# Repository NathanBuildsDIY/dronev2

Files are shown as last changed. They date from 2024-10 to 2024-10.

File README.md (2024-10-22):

See the accompanying youtube video series on @NathanBuildsDIY channel for details on how to build all of this and get it going - https://youtu.be/KzYfzi7Ct5Y
There are 5 parts

1. Collect parts - 3d print all the files here on a large format 3d printer, buy the motors/raspberry pi/drone parts in the parts list
2. Assemble the drone and landing pad per the youtube video.  See electrical schematics here as well.
3. Set up windows laptop + arduino that's used to control the drone and landing pad/battery swap station
4. Set up the raspberry pi, collect sample images and train your custom image classification model to identify the weeds in your field
5. Create waypoints files to cover your field and deploy the drone to spray weeds!

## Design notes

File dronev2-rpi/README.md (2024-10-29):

1. Log into your new raspberry pi zero 2 w
2. sudo apt-get -y install git #<-- install git
3. git clone https://github.com/NathanBuildsDIY/dronev2 #<-- pull down this git to the rpi
4. mv dronev2/dronev2-rpi . #<-- pull out the dronev2-rpi directyory from this repo to its own directory 
5. bash install_rpi_drone.sh #<-- run the setup script. It will install all libraries and set up the pi to auto-run the script that takes photos and (if the tflite model is present) classify those photos and turn on the sprayer

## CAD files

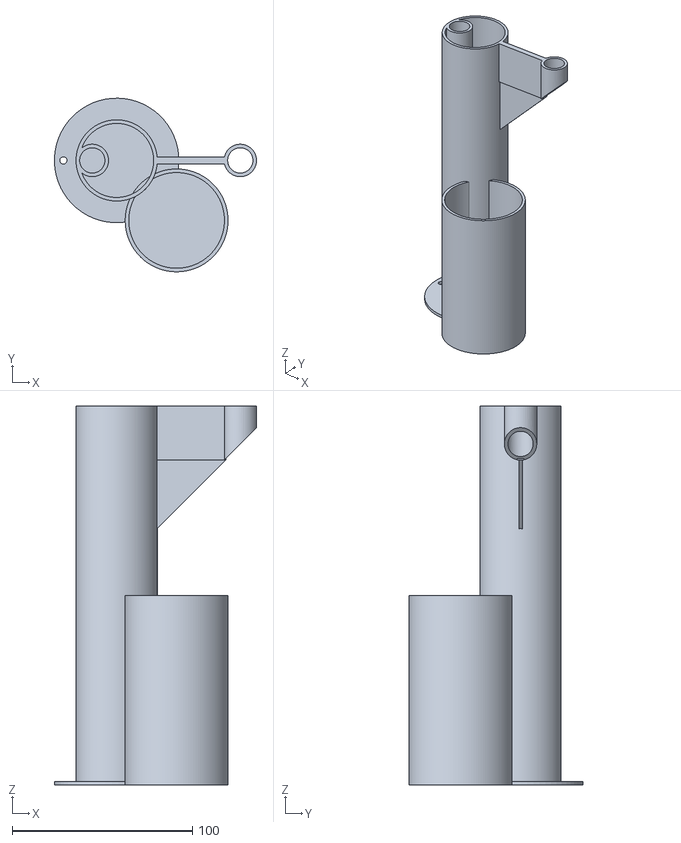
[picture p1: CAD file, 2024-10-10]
3D-Models/droneCup.stl
112.0 x 96.2 x 210.0

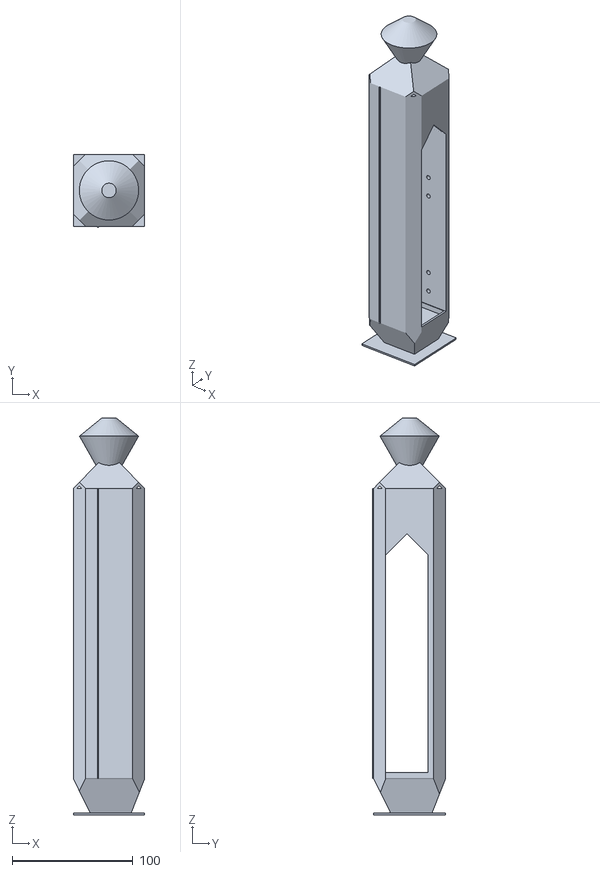
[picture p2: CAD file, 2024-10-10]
3D-Models/droneBatteryCage_v2.4.stl
59.0 x 60.5 x 328.2

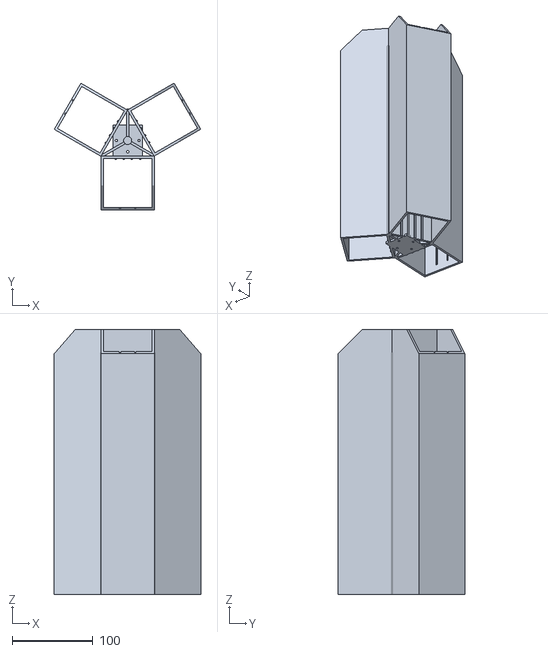
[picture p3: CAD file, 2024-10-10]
3D-Models/droneChargerSpinner_v2.1.stl
181.5 x 157.2 x 328.2

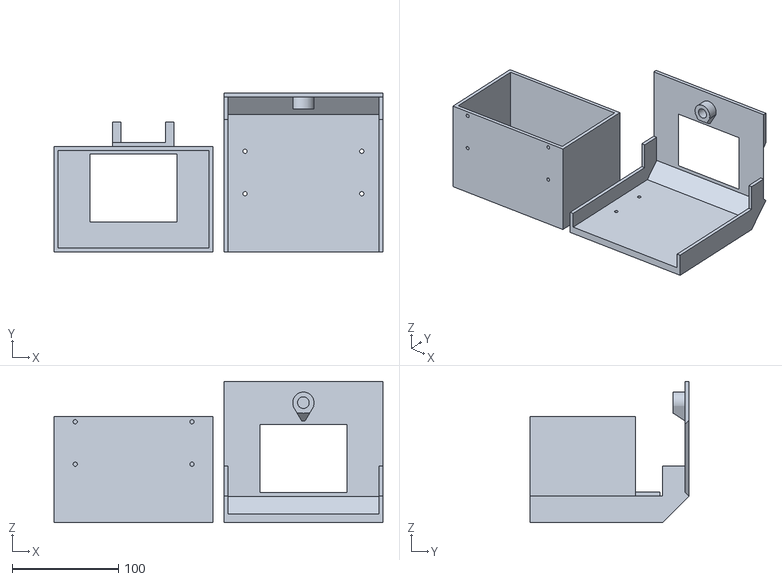
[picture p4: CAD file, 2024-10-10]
3D-Models/droneMotorSpinnerHarness_v2.stl
310.0 x 150.0 x 133.0

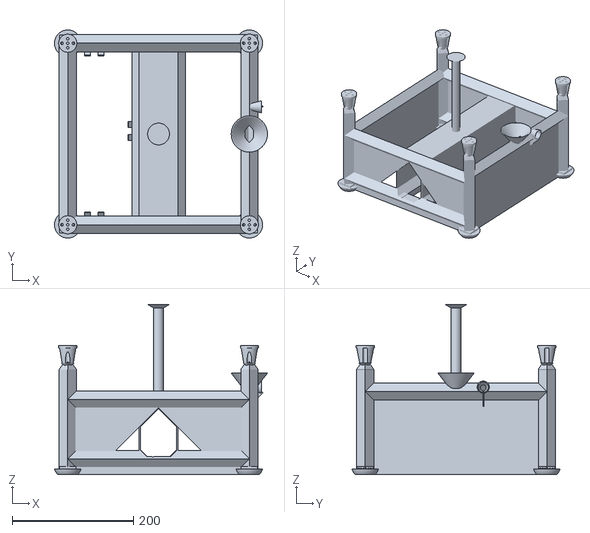
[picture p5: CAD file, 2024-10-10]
3D-Models/droneBase_v2.3.stl
351.9 x 343.8 x 281.2

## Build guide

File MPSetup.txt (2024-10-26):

Mission planner set up. 
	Great references - ardupilot - initial setup and first flight pages.  https://ardupilot.org/copter/docs/initial-setup.html
  Install mission planner
  Firmware load (usb).  Frame type. 
Remove the USB cable from your cube orange, we're going to try to conn ct to it via the 900MHz radio instead.  connect the battery to your drone to power it up then plug your 900mhz radio into your laptop via the USB port. You may havccc v cto install some drivers for the 900mhz radio via USB or you may have to read a bit on the ardupilot pages about configuration, but for me windows grabbed the drivers and it connected when I had mission planner "auto" connected to the drone, no configuration required    c 7u[ cv  b   v cccccccccccccccccccccccccccccccccccccccccccccccccccc v    
  Special setup for orange/here3+  New setup: cube orange/here3
    https://docs.cubepilot.org/user-guides/here-3/here-3-manual - had to make changes to     parm list to get here3 recognized and used.
CAN_D1_PROTOCOL: 1 set virtual driver of CAN1 to DRONECAN
CAN_D2_PROTOCOL: 1 set virtual driver of CAN 2 to DRONECAN
CAN_P1_DRIVER: 1 set this parameter to enable CAN 1 bus
CAN_P2_DRIVER: 1 set this parameter to enable CAN 2 bus
GPS_TYPE: 9 set the communication protal type of GPS 1 to DRONECAN
NTF_LED_TYPES: 231 Set to DRONECAN for LED type
There is no external safety switch. Set BRD_SAFETYENABLE as 0 to disable safety switch, or connect an physical external safety switch
Click "Write Params" when done. CAN functions will be available after rebooting the flight controller.
    Also setup for new cube orange
    fs_thr_enable - disable to allow no rc controller
    arming_check - disable check boxes
    brd_safetyenable - disable
    Then may have to disable "other" gps though it results in higher ekf
  Connect via radio.  accel, compass, esc cal (skip radio - we don't have controls to fly)
  Special configuration to auto fly. 
	initial setup - flight modes
	failsafes
	prearm safety check
	Other settings to customize
	AUTO_OPTIONS: Auto mode options
	0     Allow Arming
	1     Allow Takeoff Without Raising Throttle
	2     Ignore pilot yaw
 	   Object Detection - Connect to gps2 on cube orange.  (serial 4). 
	   SERIAL4_PROTOCOL = 9 OLD SETTINGS: ORANGE 5  (serial3 = gps, 5) (serial 1/2 = 1)
 	   SERIAL4_BAUD = 115 OLD SETTINGS: ORANGE 38 (serial3 = 38)  (serial1/2 = 57)
 	   RNGFND1_TYPE = 20     YES THIS ONE ONLY ON ORANGE
 	   RNGFND1_MIN_CM = 10
 	   RNGFND1_MAX_CM = 300
 	   RNGFND1_GNDCLEAR = 10
 	   TEST SONAR = flight control, status, sonarrange (17.95?), sonarvoltage
  Leica/base station.

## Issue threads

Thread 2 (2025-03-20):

Bridging the gap between tech and farmers

moreltay, 2025-03-20:
Nathan,

I came across your youtube channel and your amazing autonomous drone sprayer.
I am the founder of Agri Spray Drones. We one of the largest suppliers of spray drones in the country.
Our mission is to Empower Rural America and we do that through providing this technology which creates opportunities for people in rural communities to start businesses providing application services to farmers.

We also have a youtube channel dedicated mostly to educating farmers on the different drone tech available, features and benefits, and use cases.
Here is a spot spraying video of a job that we did that is similar to what your drone does, with much less automation of course. https://www.youtube.com/watch?v=cEvHZr4KTSc&t

Most of our drones are much larger than yours, carrying close to 20 gallons and designed for broad acre application.
I have started working on a very similar project to yours for automated refill and battery swap of our large drones. We are working with a drone manufacturer now that allows us much more flexibility on software and hardware customizations.

I would very much so be interested in working with you to create a much larger version of your automated drone system. I believe this would be a huge benefit for farmers to reduce costs and chemical use. That is what they want, but we have to make it easy to use and to understand.

I would really like to meet with you to talk about your drone project.
Here is my email and cell phone number. Please let me know when you have time for a call.
taylor@agrispraydrones.com
816-258-3296

PS. I am also a bit of a DIY creator. I have a non profit where I create mobility devices for children with disabilities. You can see more here.
https://www.facebook.com/frogmobilityllc
https://thefrogfoundation.org/

Thank you,
Taylor Moreland

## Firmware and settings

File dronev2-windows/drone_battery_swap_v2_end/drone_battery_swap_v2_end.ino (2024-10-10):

#include <ezButton.h>
#include <Servo.h>
// initialize pins
int generic_dir = 6;
int leftBat = 5;
int rightBat = 8;
int farArm1 = 11; 
int nearArm1 = 7;
int water = 12;
int arm2 = 9;
int relaunch = 10;
int relaunchL = 4;
int demo = 0;
int demoButton = 3; int demoButtonState = 0;
int fullRun = 1;
//Servo lBatSpin;
//Servo rBatSpin;
//ezButton landing2_limit(13); //history

// the setup function runs once when you press reset or power the board
void setup() 
{
  pinMode(generic_dir, OUTPUT); 
  pinMode(leftBat, OUTPUT); 
  pinMode(rightBat, OUTPUT);
  pinMode(farArm1, OUTPUT); 
  pinMode(nearArm1, OUTPUT);
  pinMode(water, OUTPUT);
  pinMode(arm2, OUTPUT);
  pinMode(relaunch, OUTPUT);
  pinMode(relaunchL, OUTPUT); 
  pinMode(demoButton, INPUT);
  pinMode(LED_BUILTIN, OUTPUT);
  //lBatSpin.attach(A1);
  //rBatSpin.attach(A0);
  //landing2_limit.setDebounceTime(10); //history
  Serial.begin(9600);
}

// the loop function runs over and over again forever
void loop() 
{ 
  //3. push back out onto landing pad  estimate 5 mins
  if (demo == 1){waitForPress();}//wait for demo button to be pushed if demo is active
  moveMotor(generic_dir, arm2, 255, 70000, 0); //pull back retrieve arm, clear space on pad
  moveMotor(generic_dir, arm2, 145, 5000, 0); //slow to limit
  if (demo == 1){waitForPress();}//wait for demo button to be pushed if demo is active
  moveMotor2(generic_dir, relaunch, 255, relaunchL, 255, 95000, 0); //push drone out onto pad with arm
  moveMotor2(generic_dir, relaunch, 255, relaunchL, 255, 100000, 1); //retract arm
  if (demo == 1){waitForPress();}//wait for demo button to be pushed if demo is active
  moveMotor2(generic_dir, farArm1, 255, nearArm1, 255, 30000, 0); //move short arms back out to clear space for takeoff
  moveMotor2(generic_dir, farArm1, 100, nearArm1, 145, 4000, 0); //slow to limit
  exit(0);
}

void waitForPress(){
  //waits for button to be pressed in demo mode
  Serial.print("waiting for button push");
  demoButtonState = digitalRead(demoButton);
  while(demoButtonState == LOW) {
    demoButtonState = digitalRead(demoButton);
    digitalWrite(LED_BUILTIN, HIGH);
    delay(300);
    digitalWrite(LED_BUILTIN, LOW);
    delay(300);
  }
}

int moveMotor(int dir_pin, int pwm_pin, int speed, long milliseconds, int dir){
  //move a single motor for a given time
  //set motor direction
  if (dir == 1) {
    digitalWrite(dir_pin, HIGH);
  }
  else {
    digitalWrite(dir_pin, LOW);
  }
  analogWrite(pwm_pin, speed); //start motor movin
  delay(milliseconds); //delay for duration desired
  analogWrite(pwm_pin, 0); //stop motor movin
  delay(1000); // let the power supply and motors sit idle for a moment
  return 1;
}

int moveMotor2(int dir_pin, int pwm1_pin, int pwm1_speed, int pwm2_pin, int pwm2_speed, long milliseconds, int dir){
  //start and stop moving 2 motors at the same time, run them for a given time
  //set motor direction
  if (dir == 1) {
    digitalWrite(dir_pin, HIGH);
  }
  else {
    digitalWrite(dir_pin, LOW);
  }
  analogWrite(pwm1_pin, pwm1_speed); //start motor1 moving
  analogWrite(pwm2_pin, pwm2_speed); //start motor2 moving
  delay(milliseconds); //delay for duration desired
  analogWrite(pwm1_pin, 0); //stop motor1 moving
  analogWrite(pwm2_pin, 0); //stop motor2 moving
  delay(1000); // let the power supply and motors sit idle for a moment
  return 1;
}

int moveMotor2Start(int dir_pin, int pwm1_pin, int pwm1_speed, int pwm2_pin, int pwm2_speed, long milliseconds, int dir){
  //start moving 2 motors at the same time, no stop time set
  //set motor direction
  if (dir == 1) {
    digitalWrite(dir_pin, HIGH);
  }
  else {
    digitalWrite(dir_pin, LOW);
  }
  analogWrite(pwm1_pin, pwm1_speed); //start motor1 moving
  analogWrite(pwm2_pin, pwm2_speed); //start motor2 moving
  delay(1000); // let the power supply and motors sit idle for a moment
  return 1;
}

int moveMotor2Stop(int pwm1_pin, int pwm2_pin){
  //stop moving 2 motors at the same time
  analogWrite(pwm1_pin, 0); //stop motor1 moving
  analogWrite(pwm2_pin, 0); //stop motor2 moving
  delay(1000); // let the power supply and motors sit idle for a moment
  return 1;
}

int moveMotorLimit(int dir_pin, int pwm_pin, long milliseconds, int dir, ezButton limitSwitch){
  //move motor to a limit switch. 
  //set motor direction
  if (dir == 1) {
    digitalWrite(dir_pin, HIGH);
  }
  else {
    digitalWrite(dir_pin, LOW);
  }
  long startMillis = millis(); //get initial time
  long currentMillis = millis();
  limitSwitch.loop();
  int initState = limitSwitch.getState(); //get initial state
  int curState = limitSwitch.getState(); 
  analogWrite(pwm_pin, 255); //start motor moving
  //turn on motor until the milliseconds are pass OR the limit switch is hit
  while((currentMillis - startMillis <= milliseconds) && (initState == curState)) {
    limitSwitch.loop();
    curState = limitSwitch.getState();
    currentMillis = millis();
  }
  analogWrite(pwm_pin, 0); //stop motor moving
  delay(1000); // let the power supply and motors sit idle for a moment
  return 1;
}

int moveMotorLimit2(int dir_pin, int pwm1_pin, int pwm1_speed, int pwm2_pin, int pwm2_speed, long milliseconds, int dir, ezButton limitSwitch1, ezButton limitSwitch2){
  //move 2 motors to a limit switch, each will turn off when its limit is hit, but the other can continue running to limit even if the first is already there and stopped
  //set motor direction
  if (dir == 1) {
    digitalWrite(dir_pin, HIGH);
  }
  else {
    digitalWrite(dir_pin, LOW);
  }
  long startMillis = millis(); //get initial time
  long currentMillis = millis();
  limitSwitch1.loop();
  limitSwitch2.loop();
  int initState1 = limitSwitch1.getState(); //get initial state 1
  int curState1 = limitSwitch1.getState(); //get cur state 1
  int initState2 = limitSwitch2.getState(); //get initial state 2
  int curState2 = limitSwitch2.getState(); //get cur state 2
  analogWrite(pwm1_pin, pwm1_speed); //start motor1 moving
  analogWrite(pwm2_pin, pwm2_speed); //start motor2 moving
  //turn on motors until the milliseconds are passed OR the limit switches are hit
  int counterLimit1 = 0;
  int counterLimit2 = 0;
  while((currentMillis - startMillis <= milliseconds) && ((counterLimit1 == 0) || (counterLimit2 == 0))) {
    limitSwitch1.loop();
    limitSwitch2.loop();
    curState1 = limitSwitch1.getState();
    curState2 = limitSwitch2.getState();
    if(initState1 != curState1){
      analogWrite(pwm1_pin, 0); //limit reached, stop motor1 moving
      counterLimit1 = 1;
    }
    if(initState2 != curState2){
      analogWrite(pwm2_pin, 0); //limit reached, stop motor2 moving
      counterLimit2 = 1;
    }
    currentMillis = millis();
  }
  analogWrite(pwm1_pin, 0); //stop motor1 moving
  analogWrite(pwm2_pin, 0); //stop motor2 moving
  delay(1000); // let the power supply and motors sit idle for a moment
  return 1;
}

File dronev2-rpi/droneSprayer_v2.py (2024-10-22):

import os
import time
from picamera2 import Picamera2, Preview
from datetime import datetime
from tflite_support.task import core
from tflite_support.task import processor
from tflite_support.task import vision
import cv2
import os
import os.path
import imutils
from gpiozero import LED

#set up camera
camera = Picamera2() #declare camera
config = camera.create_preview_configuration()
#camwidth = 1440 
#camheight = 1080
#config = picam.create_preview_configuration(main={"size": (camwidth, camheight)})
camera.configure(config)
camera.start()

#create run directory to save photos and go there
dronedir = os.path.expanduser("~/dronev2-rpi/")
date = datetime.now().strftime("%m_%d_%I_%M_%S_%p_%f")
rundir = dronedir+date
os.makedirs(rundir)
os.chdir(rundir)

#define sprayer pin
sprayer = LED(14)
sprayer.off()

#decide if there is an image classification model
imageModelPresent = False
if os.path.isfile(dronedir + "model_int8.tflite"):
  imageModelPresent = True
  print("Image Classification Model Exists, load it")
  # Initialize the image classification model. This is the custom trained model based on mobilenet
  base_options = core.BaseOptions(
    file_name=os.path.expanduser('~/dronev2-rpi/model_int8.tflite'), use_coral=False, num_threads=4)
  # Enable Coral by this setting
  classification_options = processor.ClassificationOptions(
    max_results=2, score_threshold=0.0)
  options = vision.ImageClassifierOptions(
    base_options=base_options, classification_options=classification_options)
  classifier = vision.ImageClassifier.create_from_options(options) 

while True:
  #take a photo
  date = datetime.now().strftime("%m_%d_%I_%M_%S_%p_%f") #note: keep it short and don't allow : in filename - error
  photo_name = date + ".jpg"
  camera.capture_file(photo_name)

  if imageModelPresent == True: 
    #Load the image
    image = cv2.imread(photo_name) #pull up image and get shape

    # Convert the image from BGR to RGB as required by the TFLite model.
    rgb_image = cv2.cvtColor(image, cv2.COLOR_BGR2RGB)
    re_size = (224,224)
    rgb_image=cv2.resize(rgb_image,re_size)

    # Create TensorImage from the RGB image
    tensor_image = vision.TensorImage.create_from_array(rgb_image)
    # List classification results
    categories = classifier.classify(tensor_image)
    category = categories.classifications[0].categories[0]

    #Label Image
    category_name = category.category_name
    score = round(category.score, 2)
    result_text = category_name + ' (' + str(score) + ')'

    #If Weed, turn on sprayer
    if category_name.startswith("weed") and score > 0.6:
      print("Found weed, turning on sprayer")
      sprayer.on()
      cv2.putText(image,category_name,(10,200),cv2.FONT_HERSHEY_PLAIN, 4, (0,0,255), 8) #image, text, (x,y), fontname, fontsize, color, thickness)
      cv2.putText(image,str(score),(10,400),cv2.FONT_HERSHEY_PLAIN, 4, (0,0,255), 8) #image, text, (x,y), fontname, fontsize, color, thickness)
    else:
      sprayer.off()
      cv2.putText(image,category_name,(10,200),cv2.FONT_HERSHEY_PLAIN, 4, (0,255,0), 8) #image, text, (x,y), fontname, fontsize, color, thickness)
      cv2.putText(image,str(score),(10,400),cv2.FONT_HERSHEY_PLAIN, 4, (0,255,0), 8) #image, text, (x,y), fontname, fontsize, color, thickness)
 
    #write out labelled image
    cv2.imwrite(result_text+photo_name,image)
      
camera.close()
